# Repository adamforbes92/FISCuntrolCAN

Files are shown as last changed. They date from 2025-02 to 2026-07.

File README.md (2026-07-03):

# FISCuntrolCAN

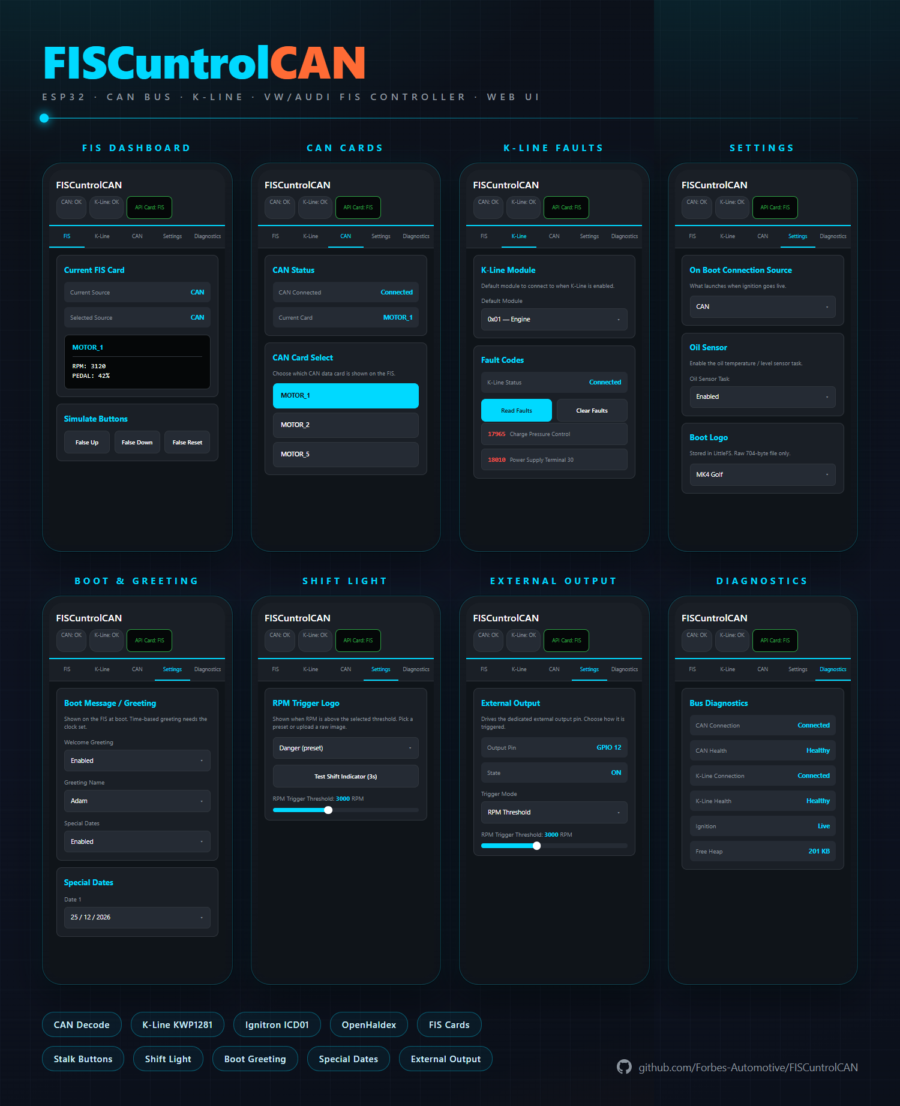
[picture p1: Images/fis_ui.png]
FISCuntrolCAN web UI


FISCuntrolCAN turns the **FIS** — the driver-information display in the middle of a VW/Audi instrument cluster — into a live data screen for your engine and chassis. It reads the car's **chassis CAN bus** (speed, RPM, pedal, Haldex, EML/EPC) and can also talk **KWP1281 over K-line** for diagnostic measuring blocks and fault codes, then displays it all onto the cluster as scrollable "cards" you flick through with the wiper-stalk buttons. It additionally decodes a standalone **Ignitron** ECU broadcast, co-operates with an **OpenHaldex** controller, and is configured entirely from a phone over **Wi-Fi** — no laptop or serial cable needed in the car. OTA updates and live diagnostics.

It is based on an **ESP32 DevKit V1 (WROOM-32)** running the Arduino framework, and is built around the excellent [TLBFISLib](https://github.com/domnulvlad/TLBFISLib), [KLineKWP1281Lib_ESP32](https://github.com/domnulvlad/KLineKWP1281Lib_ESP32) and [TLBLib](https://github.com/domnulvlad/TLBLib) libraries by `domnulvlad`, which implement the proprietary 3-wire FIS protocol and the KWP1281 diagnostic protocols.

---

## Features at a Glance

| Feature | Detail |
|---|---|
| CAN input | 500 kbit/s TWAI, accept-all filter — VAG MOTOR / Haldex / Ignitron decoders |
| K-line input | KWP1281 measuring blocks + fault-code read/clear (Engine, Gearbox, ABS, Airbag, Cluster) |
| FIS output | Live "cards" drawn over the proprietary 3-wire FIS bus via a level shifter |
| On-screen menu | Stalk-button driven SOURCE menu (K-Line / CAN / Ignitron / Haldex / Settings / Exit) |
| Ignitron view | Decodes the dashCAN "ICD01" sensor broadcast on `0x600–0x604` into paged cards |
| OpenHaldex | Broadcasts mode + pedal threshold + override so a Haldex controller can co-operate |
| Stalk control | Mimics / pulses the three stalk-button outputs to drive the cluster's own menus |
| Wi-Fi UI | Web app — config, diagnostics, OTA |
| OTA updates | Firmware **and** filesystem (web UI) flashed from the browser |
| Boot screens | Selectable splash bitmaps, or a personalised time-of-day greeting |
| Special dates | Up to 5 custom multi-line messages shown on matching calendar days (override the logo) |
| Device clock | Browser-synced time (no NTP needed in AP mode), optional DS1307 RTC, persisted to EEPROM |
| RPM shift light | Full-screen logo overlay above a configurable RPM threshold |
| Oil sensor | Optional single-wire Hella/VAG G266 oil level + temperature decoder *WIP* |
| Power management | Auto Wi-Fi-off + CPU scaling 1 min after the last client disconnects |
| Remembers settings | Nav state and configuration stored to ESP32 Preferences (NVS) |

---

## Compatibility

Designed for VW/Audi clusters that carry a **FIS** driven by the 3-wire
(`ENA` / `CLK` / `DATA`) protocol — e.g. MK4 Golf / Bora, B5–B6 Passat, and
contemporary Audi A3 / A4 / TT clusters. CAN decoding targets the classic VAG
powertrain frame set (`MOTOR1/2/5`, `HALDEX`), and K-line targets KWP1281
control modules. The Ignitron view targets the dashCAN "ICD01" custom-CAN
broadcast.

> Frame IDs, decoders and calibration are car-specific. Treat the supplied
> decoders as a known-good MK4 baseline and adjust [`config.h`](include/config.h)
> to suit your vehicle.

---

## Hardware Overview

### External Interfaces

| Function | Part / circuit |
| --- | --- |
| CAN transceiver | TJA1050 / MCP2551 / SN65HVD230 — 500 kbit/s |
| K-line transceiver  | KWP1281-capable transceiver (e.g. L9637, MC33290) |
| FIS bus | 5 V cluster lines through a CJ74LVC4T245 level shifter (bidirectional `ENA`, unidirectional `CLK` / `DATA`) |
| Stalk buttons | One isolated input + one isolated output per stalk button (UP / DOWN / RESET) |
| Ignition sense | Resistor divider into GPIO 35 (ADC, with hysteresis) |
| External output | GPIO for switching an aux load via a driver |
| Optional RTC | DS1307 on I²C (SDA GPIO 21 / SCL GPIO 22) — enable with "Use RTC" in the UI |
| Optional oil sensor | 12 V → 3.3 V level-shifted PWM signal on GPIO 4 *WIP* |

### Pin Map

Defined in [`include/config.h`](include/config.h):

| Group | Signal | GPIO |
| --- | --- | --- |
| FIS (SPI) | CLK | 18 |
| | DATA (MOSI) | 23 |
| | ENA (CS) | 19 |
| | ENADIR (level-shifter direction)  | 32 |
| K-line | TX / RX | 17 / 16 |
| CAN / TWAI | RX / TX | 13 / 14 |
| Stalk in | UP / DOWN / RESET | 34 / 39 / 36 |
| Stalk out | UP / DOWN / RESET | 27 / 26 / 25 |
| Misc | Ignition (ADC) | 35 |
| | External output | 12 |
| | Oil sensor (optional) | 4 |
| | RTC I²C SDA / SCL (optional) | 21 / 22 |

> **Input-only pins:** GPIO 34 / 36 / 39 have no internal pull-ups. The PCB
> must supply the pull-ups for the stalk inputs and the ignition-sense divider.

### Board

The reference hardware is the **FISCuntrol V3** board (Forbes Automotive),
built around an ESP32 DevKit V1 (WROOM-32) with an on-board switching
regulator, CAN and K-line transceivers, the FIS level shifter, and a single
18-way MX23A18NF1 connector.

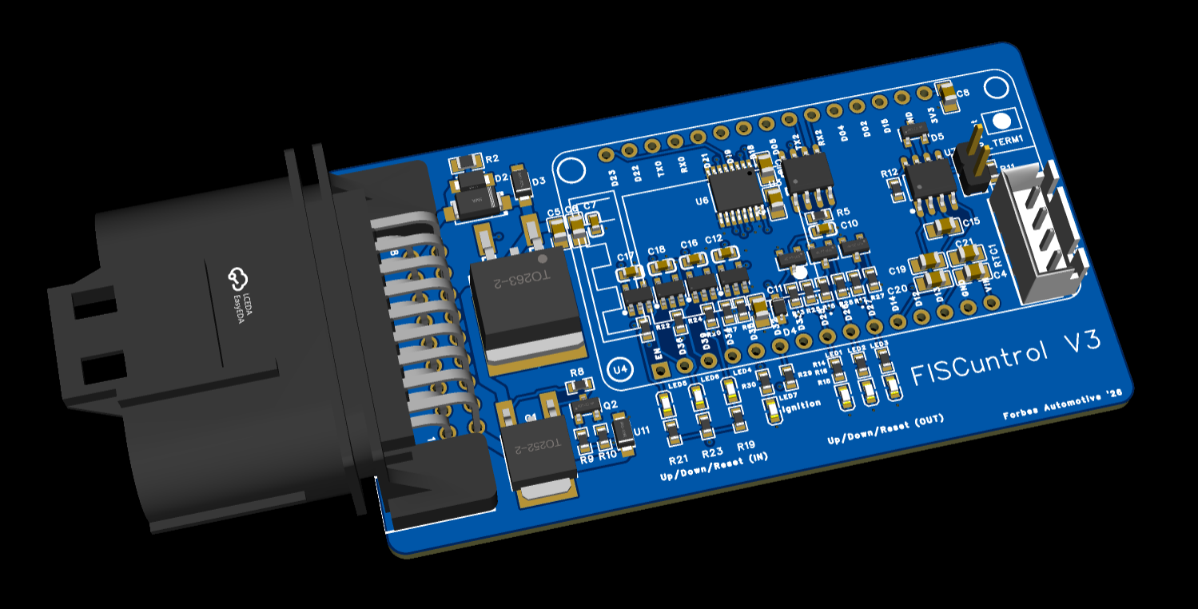
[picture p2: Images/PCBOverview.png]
FISCuntrol V3 board overview


### Harness Connector

All vehicle wiring lands on one **18-way** MX23A18NF1 connector (two rows of 9). Pin 1 is
top-right, pin 9 top-left; pin 10 is bottom-right, pin 18 bottom-left when
looking into the mating face.

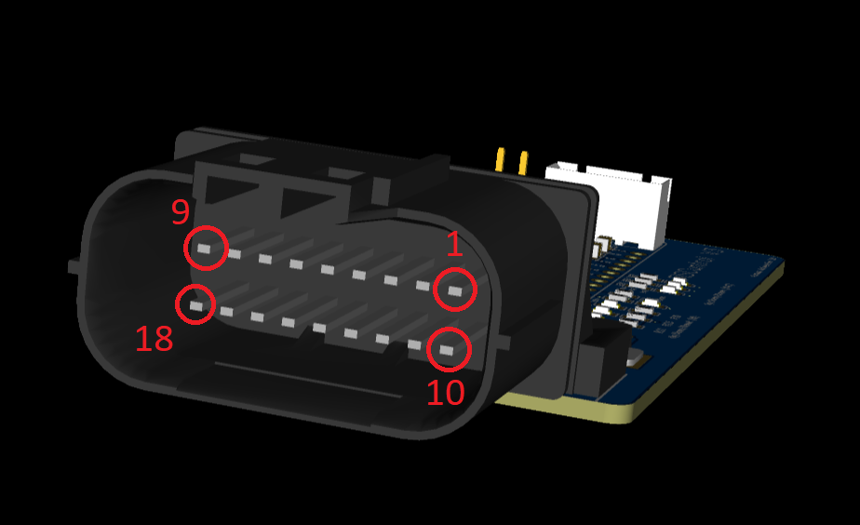
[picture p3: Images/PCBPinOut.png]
Connector pin numbering


| Pin | Silk name | Function | Internal net / GPIO |
| --- | --- | --- | --- |
| 1 | `EXT_OUT` | Switched external / aux output | GPIO 12 |
| 2 | — | Not connected | — |
| 3 | — | Not connected | — |
| 4 | `IN_UP_CONN` | Stalk **UP** button input | GPIO 34 |
| 5 | `IN_DOWN_CONN` | Stalk **DOWN** button input | GPIO 39 |
| 6 | `IN_RESET_CONN` | Stalk **RESET** button input | GPIO 36 |
| 7 | `OUT_UP_CONN` | Stalk **UP** output (drive to cluster) | GPIO 27 |
| 8 | `OUT_DOWN_CONN` | Stalk **DOWN** output (drive to cluster) | GPIO 26 |
| 9 | `OUT_RESET_CONN`  | Stalk **RESET** output (drive to cluster)  | GPIO 25 |
| 10  | `CHASSIS_CANH` | Chassis CAN High | CAN transceiver (RX 13) |
| 11  | `CHASSIS_CANL` | Chassis CAN Low | CAN transceiver (TX 14) |
| 12  | `FIS_ENA_5V` | FIS **ENA** (5 V, bidirectional) | GPIO 19 via CJ74LVC4T245 |
| 13  | `FIS_DATA_5V` | FIS **DATA** (5 V) | GPIO 23 via CJ74LVC4T245 |
| 14  | `FIS_CLK_5V` | FIS **CLK** (5 V) | GPIO 18 via CJ74LVC4T245 |
| 15  | `MC33290_K` | K-line (KWP1281) via MC33290 transceiver | GPIO 17 / 16 (TX / RX) |
| 16  | `GND` | Ground | GND |
| 17  | `12V_IGN` | Ignition-switched 12 V (ignition sense) | ADC GPIO 35 (divider) |
| 18  | `12V_PERM` | Permanent 12 V supply | Regulator input |

<details>
<summary>Silkscreen close-ups</summary>

| Pins 1–6 · 10–15 | Pins 6–9 · 15–18 |
| --- | --- |
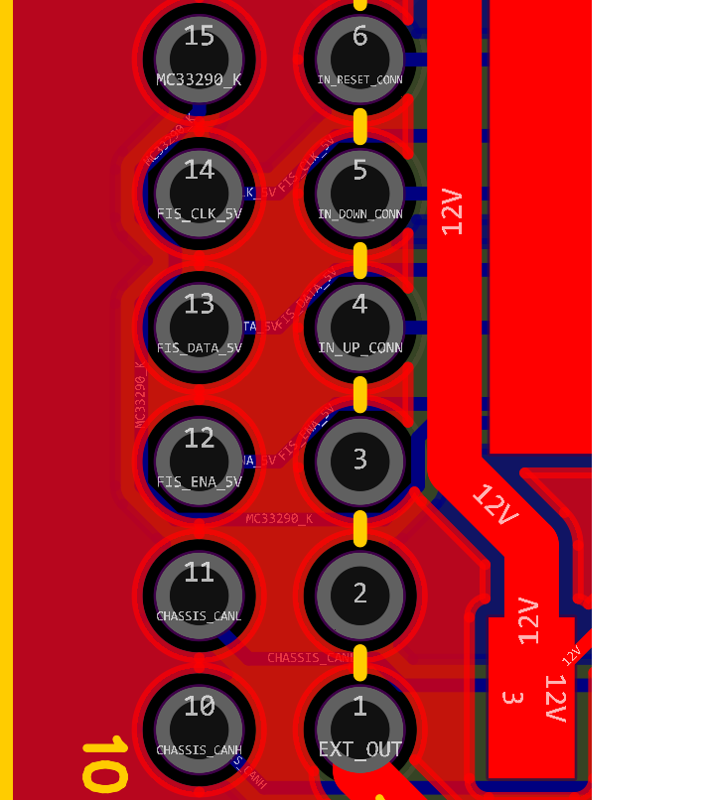
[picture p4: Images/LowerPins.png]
Lower connector pins
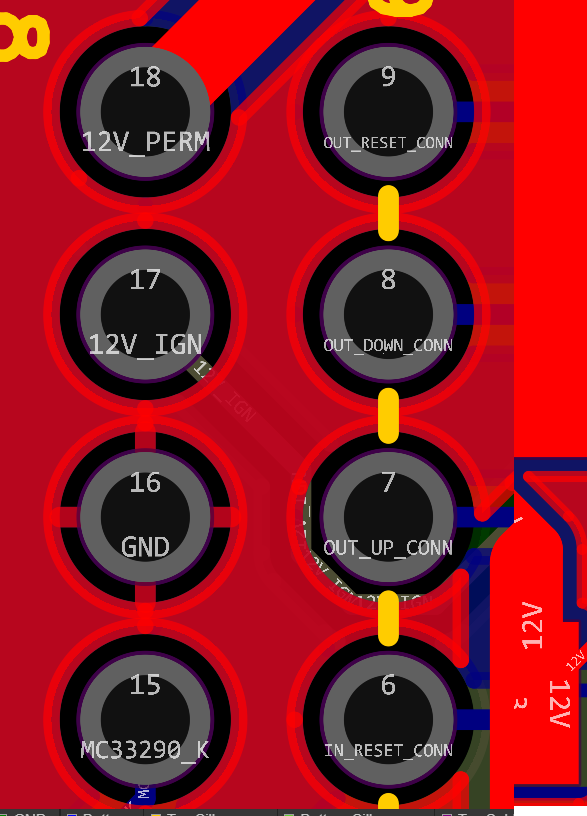
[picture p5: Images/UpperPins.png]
Upper connector pins
|  |  |

</details>

### Status LEDs

The board carries seven indicator LEDs for at-a-glance stalk and ignition I/O.

Stalk and ignition status LEDs

| LED | Group | Indicates |
| --- | --- | --- |
| LED1–LED3 | Up / Down / Reset **OUT**| Board is pulsing an output to the cluster |
| LED4–LED6 | Up / Down / Reset **IN** | A stalk button input is active |
| LED7 | Ignition | `12V_IGN` is live (ignition on) |

### CAN Termination &amp; RTC

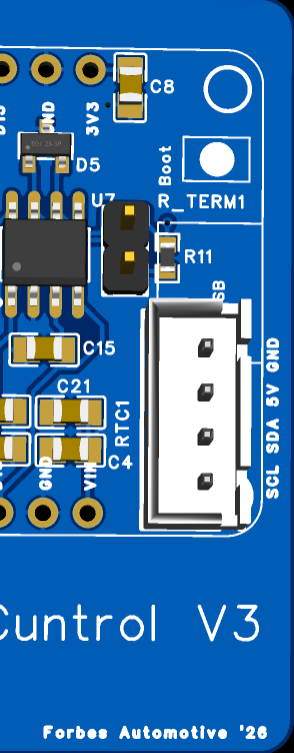
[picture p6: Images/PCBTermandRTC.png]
CAN termination jumper, boot button and RTC connector


| Feature | Detail |
| --- | --- |
| `TERM1` jumper | Fit to enable the **120 Ω** CAN bus termination; leave open when the board is not at the end of the bus |
| `RTC1` connector | 4-pin I²C header (`SCL` / `SDA` / `5V` / `GND`) for an optional DS1307 RTC module — enable with **Use RTC** in the UI (SDA GPIO 21 / SCL GPIO 22) |
| `BOOT` button  | ESP32 boot / flash button |

---

## How the Display Works

Multiple data sources feed a single shared "card" that the render task paints
onto the FIS. Only one source is shown at a time; the active source is chosen
by the on-screen menu and the stalk buttons.

```
CAN bus (500k)            K-line (KWP1281)        Ignitron ICD01 (0x600–0x604)
      │                         │                            │
      ▼ canTask (core 0)        ▼ klineTask (core 0)         ▼ canTask
 decode MOTOR1/2/5,        measuring blocks             capture frames,
 OpenHaldex, Ignitron      + fault codes                decode 16-bit signals
      │                         │                            │
      └────────────────┬────────┴────────────────────────────┘
                       ▼  shared globals  +  card store (FIS-line mutex)
                       ▼  parseFIS()  →  fisLine[0..7]
                       ▼  fisRenderTask (core 1)
                       ▼  TLBFISLib  →  FIS cluster screen
```

### Card Sources

| Source | Shows |
| --- | --- |
| `CAN` | Decoded MOTOR cards — RPM & pedal, speed, EML/EPC, plus raw bytes  |
| `IGNITRON` | Paged Ignitron ICD01 sensor values (6 signals per card) |
| `K-LINE` | KWP1281 measuring-block values for the selected module |
| `HALDEX` | OpenHaldex mode, lock target, engagement, speed, pedal |

### On-Screen Menu

Long-press **RESET** opens the **SOURCE** menu. Items appear only when their
hardware is available:

`K-LINE` (→ module sub-menu) · `CAN` · `IGNITRON` · `HALDEX` · `EXIT`

### Stalk Buttons

The three stalk buttons are read with [OneButton](https://github.com/mathertel/OneButton)
(single / double / long-press) and their meaning depends on the active source:

| Gesture | In a menu | CAN / Ignitron | Haldex | K-line |
| --- | --- | --- | --- | --- |
| UP — single | Navigate up | Next card / page | Mode + | Block +1 |
| DOWN — single | Navigate down | Previous card / page | Mode − | Block −1 |
| UP — double | — | — | — | Block +10 |
| DOWN — double | — | — | — | Block −10 |
| UP — long | — | **Toggle CAN ↔ OpenHaldex** (returns to the last CAN view) |||
| DOWN — long | — | — | — | Block → 1 |
| RESET — single | Select item | Open menu | Open menu | Open menu |
| RESET — long | Close menu | Open menu / re-enable FIS (toggles FIS off if not booted) |||

> **Last-CAN-view memory:** the long-press-UP toggle simply flips between
> OpenHaldex and the CAN view you last selected. If you were on `CAN` it
> toggles CAN ↔ OpenHaldex; if you were on `IGNITRON` it toggles
> Ignitron ↔ OpenHaldex. The choice persists across power cycles (EEP).

---

## Data Sources

### CAN Decoders

The TWAI controller runs at **500 kbit/s** with an accept-all filter, so every
frame on the bus reaches the firmware. Built-in VAG decoders:

| Frame | ID | Decoded into |
| --- | --- | --- |
| `MOTOR1` | `0x280` | `vehicleRPM`, `pedValue` |
| `MOTOR2` | `0x288` | `vehicleSpeed` (km/h, optional → mph) |
| `MOTOR5` | `0x480` | `vehicleEML`, `vehicleEPC` |
| `openHaldex`  | `0x6B0` | Haldex state, engagement, mode, speed |
| Ignitron ICD01| `0x600`–`0x604` | See [Ignitron View](#ignitron-view) |

### K-line (KWP1281)

When the boot source is K-line, the firmware connects to a control module over
the K-line and polls measuring blocks. The menu's **K-LINE** sub-menu selects
the module; reconnects are handled live with ret/fallback.

| Module  | Address |
| --- | --- |
| Engine  | `0x01`  |
| Gearbox | `0x02`  |
| ABS | `0x03`  |
| Airbag  | `0x22`  |
| Cluster | `0x23`  |

Fault codes can be read and cleared from the web UI's **K-Line** tab.

### Ignitron View

The Ignitron standalone ECU broadcasts the dashCAN **"ICD01"** custom message
set on frames `0x600–0x604`. Each frame packs four little-endian 16-bit
signals; FISCuntrolCAN captures the frames, decodes the signals (reversing the
dashCAN scale/offset) and shows them as paged cards — **6 signals per card**,
so the 20-signal map fills four pages (`IGN 1/4` … `IGN 4/4`). Page with the
UP/DOWN stalk buttons.

Decoded signals include RPM, coolant, MAP, IAT, EGT, oil pressure/temperature,
fuel rail pressure, lambda, pedal, speed, throttle position, battery voltage,
ignition advance, short/long fuel trims and ECU torque. 

### OpenHaldex

When Haldex hardware is present, a background task broadcasts a FISCuntrol
frame (`0x6A0`) carrying the selected mode every 50 ms, and reads the
OpenHaldex status frame (`0x6B0`). Modes: **Stock, FWD, 50/50, 60/40, 75/25,
Expert**. Change mode with UP/DOWN while the Haldex card is shown.

---

## Wi-Fi & Web Interface

Connect to the **`FISCuntrolCAN`** Wi-Fi access point and browse to
**`http://192.168.1.1/`**. The interface is a web app served from the
ESP32's LittleFS partition; settings auto-save to NVS.

| Tab | Purpose |
| --- | --- |
| **FIS** | Live FIS card preview, software stalk-button simulator, ignition restart |
| **K-Line** | Fault-code viewer + clear, module selector |
| **CAN** | CAN data card carousel |
| **Settings** | Boot source (CAN / K-line), boot screen, welcome greeting + name, special dates, Use RTC, per-category logging toggles, RPM-logo threshold, pin assignments, K-line default module |
| **Logos** | Upload a 704-byte boot bitmap or RPM-overlay bitmap |
| **Diagnostics** | CAN / K-line health, ignition state, free heap, FIS boot readiness, raw button-pin states, external-output control, device clock (browser / device / RTC time + RTC status) |
| **OTA** | Flash new firmware or a new filesystem image from the browser |

---

## Boot Greeting, Special Dates & Clock

The boot screen can show a **personalised greeting** instead of a logo. With
**Welcome Greeting** enabled in the **Settings** tab you enter a name only and
the device uses the time of day — `GOOD MORNING / AFTERNOON / EVENING
<name>`. The greeting and a boot logo are mutually exclusive (turning the
greeting on clears the selected logo).

**Special Dates** let you define up to **five** calendar days, each with its own
custom multi-line message. On a matching day the message is shown on boot and
**overrides the logo** for that day — even if the Welcome Greeting is off. A
date left at the `1970` is treated as unset.

Both features need the clock time. The browser POSTs its local
date/time to `/api/time` on every page load, the ESP32 advances that time with
its internal clock and **persists it to EEP** so a reboot still has an
approximate time. Enable **Use RTC** to additionally read/write a **DS1307**
on `SDA = GPIO 21` / `SCL = GPIO 22`; when present and running the RTC is
preferred on boot and kept in sync whenever the browser sets the time.

The **Diagnostics** tab's *Device Clock* panel shows the live **browser** time,
the **device** time, the **RTC** time, and the **RTC status**
(*Healthy* / *Not healthy* / *Not detected*). All greeting, special-date,
name and Use-RTC settings are stored in EEP.

---

## Power Management

The firmware bundles the universal `power_manager` module (shared with
SpeedPulser Pro / Can2Cluster) that **1 minute after the last
Wi-Fi client disconnects** will reduce CPU usage and turn off WiFi.  This reduces power consumption / heat generated.

| Action | Saving |
| --- | --- |
| Wi-Fi radio off | ~80–120 mA average (single biggest) |
| CPU 240 MHz → 80 MHz | Moderate reduction in active current |
| Bluetooth controller released at boot | ~60 KB RAM freed; small idle saving |
| Onboard LED off at boot | Tiny but persistent saving |

A power-cycle (ignition off/on) brings Wi-Fi back.

---

## Oil Sensor (Optional)
**Work In Progress!**
Decodes a single-wire Hella / VAG combined **oil-level + oil-temperature**
sensor (G266 family, OE PNs around `1J0907660*` / `06A907660*`). Disabled by
default (`hasOilSensor 0`).

- The sensor is treated as a **continuous ~18–30 Hz PWM** (not the BMW/Hella
  3-pulse frame): each cycle's **period** is mapped to oil temperature via a
  two-point linear fit, then EMA-filtered.
- The temperature fit is seeded from real MK4 G266 captures
  (~36.5 ms ≈ 20 °C, ~54 ms ≈ 100 °C). Re-check it against a dash / CAN
  oil-temperature reading.
- Oil **level** is *not* calibrated yet (`oilSensorLevelCalibrated 0`, level
  returns `NAN`) — the captures were made in water with the level pad dry.

**To calibrate:**

1. In [`config.h`](include/config.h) set `hasOilSensor 1` and `oilSensorRawLog 1`.
2. Wire the sensor's signal via a 12 V → 3.3 V level shifter to GPIO 4
   (change `oilSensorPin` for a different GPIO).
3. Watch Serial — every cycle prints
   `[OIL] period=… us (… Hz)  high=… us  low=… us  duty=…%  T=…C  cyc=… err=…`.
4. Tune the `oilSensor*` defines (`oilSensorTempPeriod0Us/…1Us` for temperature;
   the `…Period…/…Pulse…Min/Max` sanity windows) until `oilSensorFrameCount`
   rises and the temperature looks sane. For level, run an oil-bath depth test,
   set `oilSensorLevelCalibrated 1` and fill in `oilSensorLevelPulse0Us/…1Us`.

```cpp
void  setupOilSensor();                 // call from setup()
void  serviceOilSensor();               // call from loop()
float oilSensor_getTemperatureC();      // NAN if stale
float oilSensor_getLevelMm();           // NAN if stale
float oilSensor_getLevelPercent();      // 0..100, NAN if stale
bool  oilSensor_isPresent();
bool  oilSensor_hasValidReading();
```

---

## Configuration

### Feature Toggles

| Define | Default | Effect |
| --- | --- | --- |
| `enableDebug` | 1 | Mirror `DEBUG(...)` output to Serial. |
| `serialBaud` | 115200  | UART speed for the debug console. |
| `ChassisCANDebug` | 0 | Print every incoming TWAI frame. |
| `checkLED` | 0 | Run a one-shot LED test at boot. |
| `detailedDebugWiFi` | 0 | Verbose Wi-Fi events. |
| `hasRTC` | 0 | Legacy compile flag; the DS1307 RTC is now toggled at runtime via **Use RTC** in the UI. |
| `isMPH` | 1 | Convert km/h → mph (`mphFactor` constant). |
| `hasOilSensor` | 0 | Compile in the oil-sensor decoder. |
| `oilSensorRawLog` | 0 | Print every decoded oil-sensor pulse to Serial. |
| `defaultBootScreen` | 2 | 0=off, 1=text, 2=MK4Golf, 3=logo, 4=finger, 5=BMP.  |

### Timing Knobs

`fisWakeDelay`, `fisBootTimeoutMs`, `bootScreenDuration`, `logFrequency`,
`canRefresh`, `connectionDelayDuration`, `fisStatusCardHoldMs` — tune per car
if the cluster behaves differently.

---

## Software Architecture

The Arduino `loop()` runs on **core 1**; CAN reception and other long-lived
jobs run as dedicated FreeRTOS tasks on **core 0**.

### Modules

| Module | Responsibility |
| --- | --- |
| `config.*` | All compile-time defines, pin map, CAN IDs, shared globals + `extern` decls |
| `main.cpp` | `setup()` / `loop()`, ignition status, button-output + oil-sensor monitoring |
| `onboot.cpp`  | GPIO init, boot sequence, connection launch/shutdown |
| `tasks.cpp` | FreeRTOS task creation (CAN RX, FIS render, K-line poll, Haldex broadcast)  |
| `can_bus.cpp` | TWAI driver + frame capture; MOTOR + Ignitron card decode/render |
| `kline.cpp` | KWP1281 measuring-block reads + fault-code clear via Serial2 |
| `fis_display.cpp` | TLBFISLib wrapper + rendering |
| `fis_menu.cpp`| On-FIS SOURCE menu |
| `cards.cpp` | FIS "card" store with source switching (mutex-protected) |
| `buttons.cpp` | OneButton wrappers for the stalk inputs + stalk-output pulse generator |
| `bootLogos.cpp` / `bootmessage.cpp` | Boot splash bitmaps + user-configurable greeting / special-date messages |
| `timekeeper.cpp` | Device clock — browser time sync, optional DS1307 RTC, EEP |
| `web_server.cpp` | Wi-Fi AP + AsyncWebServer, JSON API, OTA, LittleFS-served UI |
| `oil_sensor.cpp` | Optional Hella oil-level + temperature decoder |

### FreeRTOS Tasks

| Task | Core | Priority | Job |
| --- | ---- | --- | --- |
| `CAN_RX` | 0 | 2 | Drain TWAI, update telemetry globals, feed Ignitron |
| `FIS_RENDER` | 1 | 2 | Render menu / card / RPM overlay / K-line / Haldex |
| `KLINE_POLL` | 0 | 1 | Poll KWP1281 measurements, handle module reconnect |
| `OH_BCAST` | 0 | 1 | Broadcast OpenHaldex frame (50 ms cadence) |

### `setup()` Order

1. `Serial.begin()` (if `enableDebug` / `ChassisCANDebug`)
2. `setupWiFi()` → `setupWebServer()` → `timeInit()`
3. `powerInit()` — start the background power-manager task
4. `initCardMutex()` — **before** any task that calls `commitCard()` / `displayFIS()`
5. `setupPins()` — GPIO directions, pull-ups, external output
6. `setupButtons()` — stalk OneButton handlers + ISRs
7. `setupOilSensor()` — attaches the edge ISR if `hasOilSensor` is on
8. `startTasks()` — launch the FreeRTOS tasks above

### `loop()` Services

ADC ignition sampling with hysteresis (20 ms) · button-output pulse servicing ·
oil-sensor pulse decode · ignition rise/fall → boot/shutdown · FIS enable/disable
toggle · 200 ms diagnostic Serial print.

---

## Technical Reference

### CAN / TWAI

| Parameter | Value |
| --- | --- |
| Baud | 500 kbit/s |
| Mode | Normal, accept-all filter |
| Driver | ESP-IDF `driver/twai.h` (native) |

### Key CAN IDs

| ID | Use |
| --- | --- |
| `0x280` / `0x288` / `0x480` | VAG `MOTOR1` / `MOTOR2` / `MOTOR5` |
| `0x600`–`0x604` | Ignitron ICD01 sensor broadcast |
| `0x6A0` | FISCuntrol → OpenHaldex mode |
| `0x6B0` | OpenHaldex → FISCuntrol status |

### PlatformIO Dependencies

| Library | Purpose |
| --- | --- |
| `me-no-dev/ESPAsyncWebServer` + `me-no-dev/AsyncTCP` | Async web server + TCP |
| `bblanchon/ArduinoJson` | JSON for the REST API |
| `mathertel/OneButton` | Stalk-button gesture decoding |
| `adafruit/RTClib` | Optional DS1307 RTC |
| `domnulvlad/TLBFISLib`  | FIS rendering over the 3-wire bus |
| `domnulvlad/KLineKWP1281Lib_ESP32` | KWP1281 diagnostic stack |
| `domnulvlad/TLBLib` | Low-level FIS transport |

Platform: `pioarduino/platform-espressif32` 54.03.20 (Arduino-ESP32 3.x / ESP-IDF 5.x).

---

## Version History

| Version | Highlights |
| --- | --- |
| **Unreleased** | Personalised boot **Welcome Greeting** (name only; device adds the time-of-day prefix) and **5 configurable special-date** messages that override the boot logo. New **timekeeper** module: browser-synced device clock (`/api/time`), optional **DS1307 RTC** on SDA 21 / SCL 22, and NVS persistence of the epoch. **Diagnostics** gained a *Device Clock* panel showing browser / device / RTC time plus RTC health. All new settings persisted to NVS. |
| **Logging & task refactor** | Categorised serial/UI logging (**SYS / CAN / K-LINE / IO / WIFI**) with per-category toggles in the UI; `parseFIS()` moved into `fis_display`, CAN tasks consolidated into `can_bus`; dedicated FreeRTOS tasks for ignition fallback, button outputs and the (UI-disable-able) oil sensor. |
| **Baseline** | CAN + K-line + Ignitron + OpenHaldex unified card system, Wi-Fi single-page UI, OTA (firmware + filesystem), RPM shift-light overlay, optional oil-sensor decoder and the shared power-management module. |

---

## Disclaimer

FISCuntrolCAN displays vehicle data for information only and interfaces with a
vehicle's diagnostic and CAN buses. Always assume readings are approximate.
Use at your own risk — incorrect frame IDs, decoders or wiring can affect bus
behaviour. Test on the bench before fitting to a car.

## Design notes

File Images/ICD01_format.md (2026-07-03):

# dashCAN `.icd` File Format (magic `ICD01`)

Reverse-engineered from `dashCAN_send_custom_CAN_Messages.icd` (2769 bytes) and
cross-checked field-by-field against the dashCAN "Import" UI. Every value below
was validated against the running tool.

## Conventions

- All multi-byte integers are **little-endian `uint32`**.
- The format is a set of **fixed-size parallel-array tables** ("columns").
  Each column is a flat array of `uint32`; row *i* of every column describes the
  same entry. A separate `uint32` count says how many rows are actually used;
  unused slots are left at their default value (often non-zero).
- Two tables exist: the **Identifier table** (the CAN frames to transmit) and
  the **Signal table** (the data packed into those frames).

## Top-level layout

| Offset  | Size | Meaning |
|---|---|---|
| `0x000` | 5 | Magic ASCII `"ICD01"` |
| `0x005` | 4 | `idCount` — number of identifiers used (here 5) |
| `0x009` | 448  | Identifier table: **7 columns × 16 rows × 4 bytes**|
| `0x1C9` | 4 | `sigCount` — number of signals used (here 20) |
| `0x1CD` | 2304 | Signal table: **9 columns × 64 rows × 4 bytes** |
| `0xACD` | 4 | Trailer / checksum (`0x000370E7` in this file) |
| `0xAD1` | — | EOF (2769 bytes total) |

`0x009 + 7*16*4 = 0x1C9` and `0x1CD + 9*64*4 = 0xACD`, so the sections abut exactly.

### Identifier table — base `0x009`, 16 rows/column, stride `16*4 = 0x40`

| Col | Offset  | Field | Notes |
|-----|---|---|---|
| 0 | `0x009` | CAN ID | 11-bit standard ID (0x600…0x604) |
| 1 | `0x049` | DLC / Length | Frame length in bytes (8) |
| 2 | `0x089` | Repeat | Repeat ÷10 → ms. `5` ⇒ **50 ms** |
| 3–6 | `0x0C9` | Reserved (zero)  | ID-type / data-init / flags — all 0 here|

### Signal table — base `0x1CD`, 64 rows/column, stride `64*4 = 0x100`

| Col | Offset  | Field | Notes |
|-----|---|---|---|
| 0 | `0x1CD` | Data type | dashCAN signal enum (see table below) |
| 1 | `0x2CD` | Multiply | Fixed-point ×1000. `1000` ⇒ **1.000** |
| 2 | `0x3CD` | Add (offset) | Raw integer offset added before scaling |
| 3 | `0x4CD` | Min | Raw clamp minimum |
| 4 | `0x5CD` | Max | Raw clamp maximum |
| 5 | `0x6CD` | Invert | 0 = normal, 1 = inverted |
| 6 | `0x7CD` | CAN ID | Which identifier this signal is packed into |
| 7 | `0x8CD` | Start bit | Bit offset within the frame (0,16,32,48…) |
| 8 | `0x9CD` | Length | Signal length in bits (16) |

Byte order is **little-endian** for all packed signals (matches the UI's
"Little endian" selection); it is not stored as a per-signal column in `ICD01`.

## Decoded contents of this file

**Identifiers** (all DLC 8, repeat 50 ms): `0x600 0x601 0x602 0x603 0x604`

**Signals** (type = dashCAN enum, scale = mul/1000, off = add):

| # | Signal name (UI) | enum  | CAN ID | start | len | mul | add  | min | max |
|---|---|---|---|---|-----|---|---|-----|---|
| 0 | Sensors RPM | 0x48  | 0x600  | 0 | 16  | 1.000 | 0 | 0 | 10000 |
| 1 | Sensors engine coolant temperature | 0x4B  | 0x600  | 16 | 16  | 1.000 | 400  | 0 | 1800  |
| 2 | Sensors manifold absolute pressure | 0x4A  | 0x600  | 32 | 16  | 1.000 | 0 | 0 | 10000 |
| 3 | Sensors intake air temperature | 0x4C  | 0x600  | 48 | 16  | 1.000 | 400  | 0 | 1800  |
| 4 | Sensors exhaust gas temperature | 0x4D  | 0x601  | 0 | 16  | 1.000 | 0 | 0 | 1200  |
| 5 | Sensors oil pressure | 0x62  | 0x601  | 16 | 16  | 1.000 | 0 | 0 | 10000 |
| 6 | Sensors oil temperature | 0x61  | 0x601  | 32 | 16  | 1.000 | 400  | 0 | 2000  |
| 7 | Sensors fuel rail pressure | 0x56  | 0x601  | 48 | 16  | 1.000 | 0 | 0 | 10000 |
| 8 | Sensors lambda | 0x4F  | 0x602  | 0 | 16  | 1.000 | 0 | 0 | 9999  |
| 9 | Sensors throttle pedal position | 0x58  | 0x602  | 16 | 16  | 1.000 | 0 | 0 | 10000 |
| 10| Sensors vehicle speed signal | 0x4E  | 0x602  | 32 | 16  | 1.000 | 0 | 0 | 3200  |
| 11| Sensors throttle position sensor | 0x59  | 0x603  | 0 | 16  | 1.000 | 0 | 0 | 10000 |
| 12| Sensors battery voltage | 0x53  | 0x603  | 16 | 16  | 1.000 | 0 | 0 | 10000 |
| 13| Ignition advance | 0x81  | 0x603  | 32 | 16  | 1.000 | 400  | 0 | 10000 |
| 14| Injection fuel trim (short term) | 0xED  | 0x603  | 48 | 16  | 1.000 | 1000 | 0 | 10000 |
| 15| Injection fuel trim (long term add.) | 0xEE  | 0x604  | 0 | 16  | 1.000 | 1000 | 0 | 10000 |
| 16| ECU Engine Output Power | 0x70  | 0x604  | 48 | 16  | 1.000 | 0 | 0 | 10000 |
| 17| Knock Amplitude | 0xF7  | 0x604  | 16 | 16  | 1.000 | 0 | 0 | 10000 |
| 18| ECU Engine Output Torque | 0x6F  | 0x602  | 48 | 16  | 1.000 | 0 | 0 | 10000 |
| 19| ECU Gear Number | 0x11B | 0x604  | 32 | 16  | 1.000 | 0 | 0 | 10000 |

### Decode/scale formula

Physical value the UI shows is derived from the raw 16-bit signal as:

```
raw   = signal bits (little-endian, unsigned)
value = (raw / multiply_fixed_x1000) ... then UI subtracts the "Add" offset
```

When *encoding* a physical value to transmit (the direction the dashboard uses):

```
raw = clamp( round(physical * (multiply/1000)) + add, min, max )
```

The `add` column is an integer pre-offset (e.g. coolant/IAT use +400 so a 0 °C
reading transmits as 400; trims use +1000 so 0 % transmits as 1000).

## dashCAN signal-type enum (the codes seen here)

| enum  | UI name |
|---|---|
| 0x48  | Sensors RPM |
| 0x4A  | Sensors manifold absolute pressure |
| 0x4B  | Sensors engine coolant temperature |
| 0x4C  | Sensors intake air temperature |
| 0x4D  | Sensors exhaust gas temperature |
| 0x4E  | Sensors vehicle speed signal |
| 0x4F  | Sensors lambda |
| 0x53  | Sensors battery voltage |
| 0x56  | Sensors fuel rail pressure |
| 0x58  | Sensors throttle pedal position |
| 0x59  | Sensors throttle position sensor |
| 0x61  | Sensors oil temperature |
| 0x62  | Sensors oil pressure |
| 0x6F  | ECU engine output torque |
| 0x81  | Ignition advance |
| 0xED  | Injection fuel trim (short term) |
| 0xEE  | Injection fuel trim (long term add.) |
| 0x70  | (unknown — not labelled in UI) |
| 0xF7  | (unknown — not labelled in UI) |
| 0x11B | (unknown — not labelled in UI) |

> Only the codes present in this file are mapped. The full dashCAN PID enum is
> larger; extend the table as new `.icd` files reveal more codes.

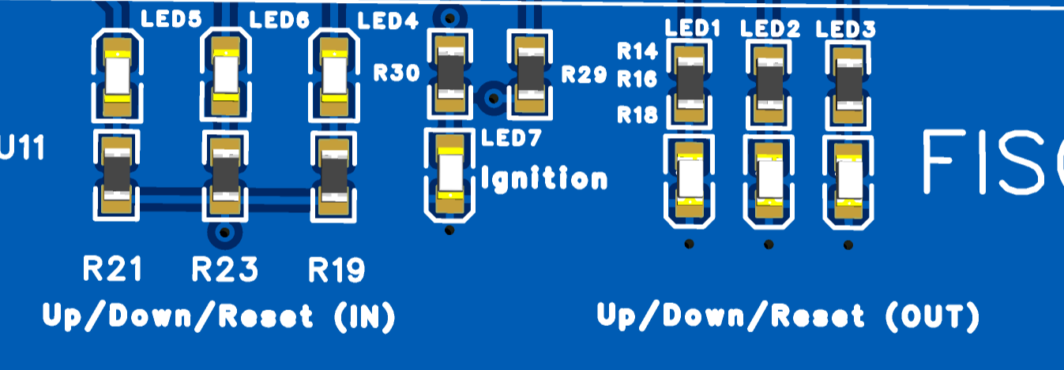
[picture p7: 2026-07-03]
Images/PCBStalkLEDs.png

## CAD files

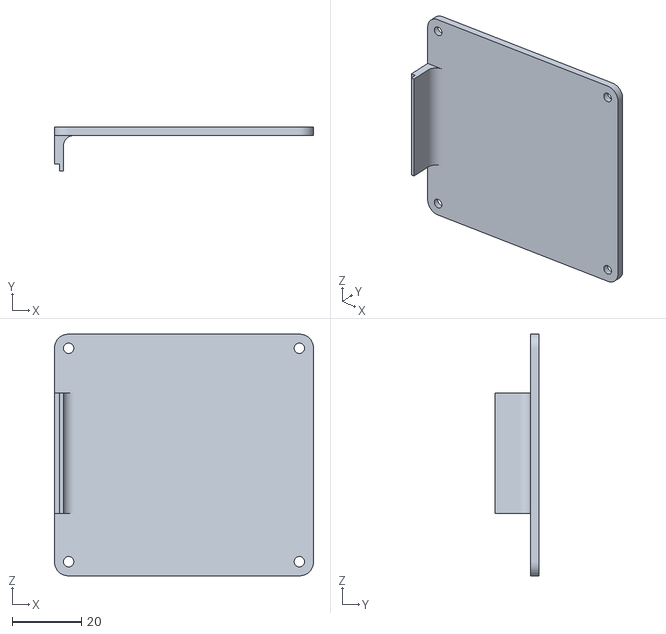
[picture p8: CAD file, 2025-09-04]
Enclosure/FISCuntrolLid.STL
75.0 x 12.6 x 70.0

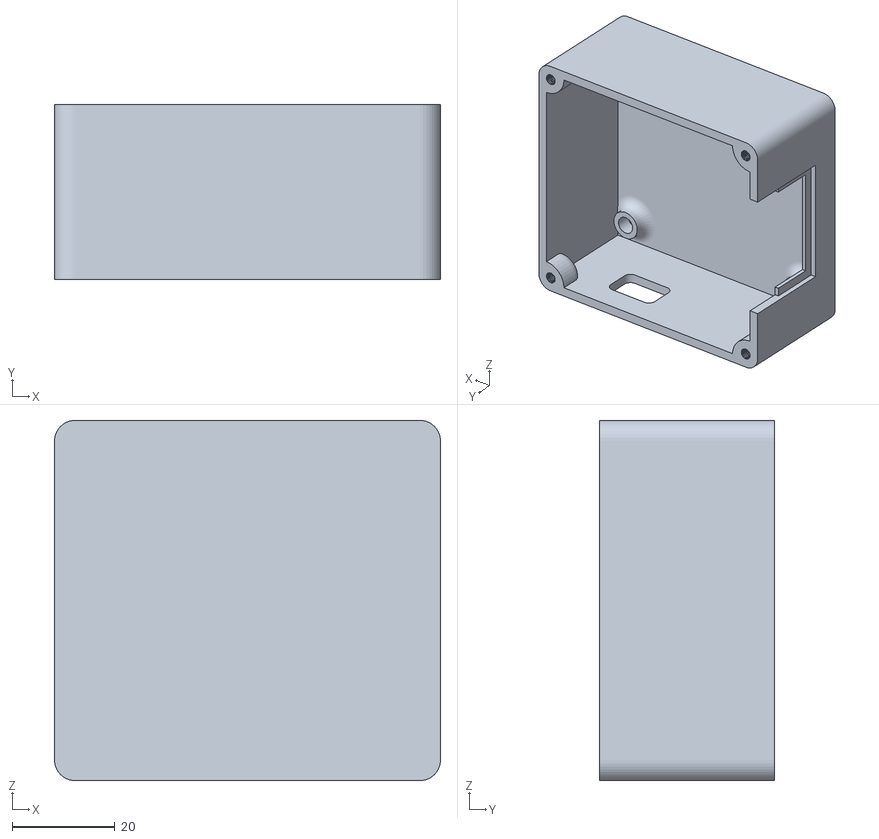
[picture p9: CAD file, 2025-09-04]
Enclosure/FISCuntrol.STL
75.0 x 34.0 x 70.0

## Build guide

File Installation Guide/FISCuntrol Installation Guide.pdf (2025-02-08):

## FISCuntrol Installation Guide

Forbes Automotive

## Contents

## Product Overview

Thank you for purchasing FISCuntrol by Forbes Automotive!

With all our products, this one is all opensource too – so you’re able to customise it to your needs. It supports custom boot messages which can be text-based or a custom logo. K-Line diagnostics, CANBUS and OpenHaldex are all supported, just select the options you have in the firmware.

The full range of options are:

- FIS Output
- Custom text-boot messages
- Custom boot logos
- K-Line
- For connection to various modules throughout the car (typically ECU)
- CANBUS
- In development, but for CAN based ECUs like Ignitron, a list of protocols to be developed
- OpenHaldex
- Pairs with OpenHaldex via. CAN messages to select or view current Haldex status
- OEM Controls
- Utilises the stock buttons for toggling through menus

At a minimum, the FISCuntrol can be used purely for boot messages and will therefore require the least amount of wiring.

## Wiring Installation

### Initial Setup

The module will come suppled with a plug only. It is the end user’s responsibility to make the final connections to the car depending on the required setup. This setup should then be paired with the appropriate firmware.

Pin Number | Basic Detail | Comments
1 | 12v Perm (K30) | Permanent power - for keeping the module awake - mainly for custom text/time based boot messages
2 | Reset (Cluster) | Reset button back to cluster
3 | 12v Ignition (K15) | Switched power (for waking up the module)
4 | Down (Cluster) | Down button back to cluster
5 | Ground (K31) | Ground - to chassis or similar
6 | Up (Cluster) | Up button back to cluster
7 | K-Line | K-Line (grey)
8 | Reset (Stalk) | Reset button to stalk
9 | FIS Clock | FIS Clock Wire (30)
10 | Down (Stalk) | Down button to stalk
11 | FIS Data | FIS Data Wire (31)
12 | Up (Stalk) | Up button to stalk
13 | FIS Enable | FIS Enable Wire (32)
14 | N/A | Not used
15 | CAN Low | CAN Low
16 | N/A | Not used
17 | CAN High | CAN High
18 | N/A | Not used

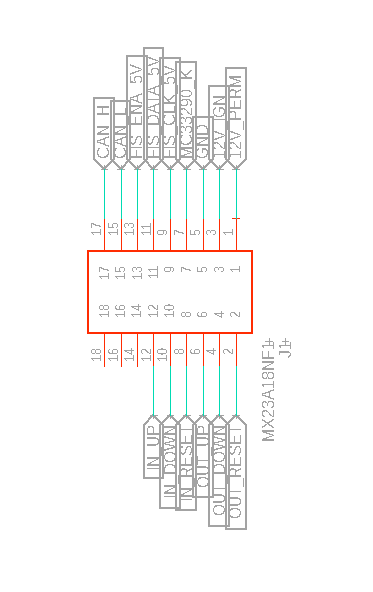
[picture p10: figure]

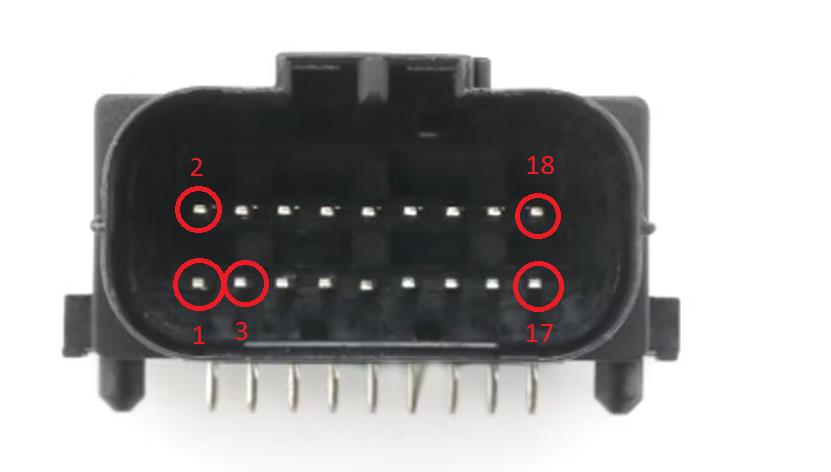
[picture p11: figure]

### Basic Operation

Using Stalk Buttons
If you have chosen to use the OEM stalk buttons as a means of interface, the default operation is to:
- Boot module, typically FIS Screen, welcome message
- Log into ECU via. K-Line or CAN
- Display variables
- ECU ‘Blocks’ can be toggled with the Up/Down buttons on the OEM stalk
- A long hold on the reset button will disable the controller to allow the OEM menus to be used

## Updating Software

Periodic firmware updates are available for download and can be uploaded to the OpenHaldex module with ease.

- Go to: https://github.com/adamforbes92/FISCuntrolCAN
- Choose the most recent software version
- Download and save locally
- Install Arduino IDE and open the downloaded software
- Ensure ESP is installed
- Use the ‘config.h’ page to adjust the features you wish to use

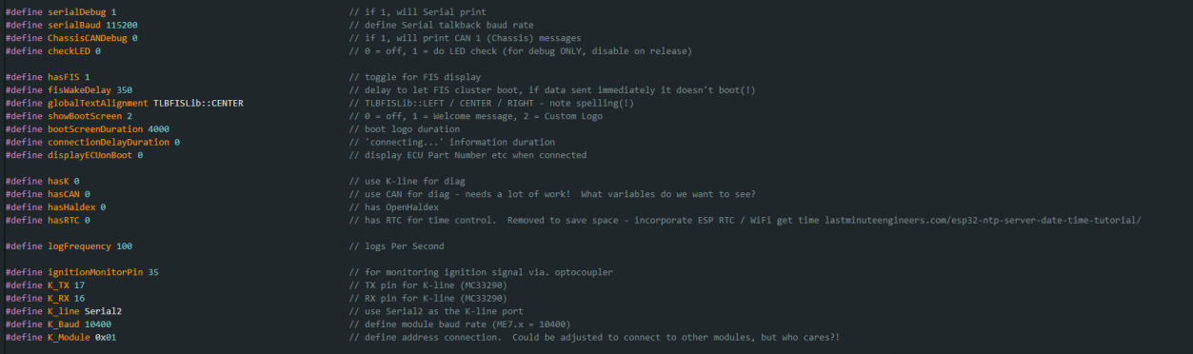
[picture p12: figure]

- From boards, select ESP32 DevKit and press compile and upload

## Disclaimer

DISCLAIMER:

Forbes Automotive is not responsible for any damage or loss that may occur to your vehicle or its contents during or after the installation of the FISCuntrol Module. By agreeing to use our product, you acknowledge that you have read and understand this disclaimer and agree to release Forbes Automotive from any liability for damages or losses.

LIMITATION OF LIABILITY:

In no event shall Forbes Automotive be liable for any direct, indirect, incidental, consequential, special, or punitive damages arising out of or in connection with the installation of the OpenHaldex T4 module, whether in contract, tort, strict liability, or any other legal theory.

This product is to be used in off-road applications only.

WARRANTY DISCLAIMER:

Forbes Automotive makes no warranties, express or implied, concerning the product, including but not limited to any warranties of merchantability or fitness for a particular purpose.

OTHER TERMS AND CONDITIONS:

By agreeing to use our services, you also agree to comply with any additional terms and conditions that may be provided to you by Forbes Automotive in connection with the product.

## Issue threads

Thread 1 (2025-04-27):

The code structure and PCB are not compatible

NesBow, 2025-04-27:
@adamforbes92 , Your code is oriented to ESP32 and the board FISCuntrol2_2024-07-14 is for MEGA PRO. Most likely the wrong PCB. I saw your new module works on ESP32

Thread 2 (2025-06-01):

Can IDs

adams-mk4-golf, 2025-06-01:
Following this, as I’m working on a canbus reader. If you need any help with the can ID addresses & functions then I can help.

adams-mk4-golf, 2025-06-02:
Hi Adam,
Please find motor can file attached. It took a long time to find & compile this data, and is the only known full list.I do have some from the comfort list too (from sniffing). I have a few notes on there, mainly the engine as there seem a few alternative IDs from older ECU to later ECU.
All addresses seem to check out.
I may need some help later on as I am not a programmer, if that would be OK
    On Monday 2 June 2025 at 19:28:25 BST, Forbes-Automotive ***@***.***> wrote:

 adamforbes92 left a comment (adamforbes92/FISCuntrolCAN#2)
Would be very handy! Currently CAN is quite bare - I'd like to build up 'blocks' to toggle through various addresses/bytes to form specific functions.

Will get messy etc with aftermarket ECUs, but worth padding out!

—
Reply to this email directly, view it on GitHub, or unsubscribe.
You are receiving this because you authored the thread.Message ID: ***@***.***>

adamforbes92, 2025-06-05:
There's nothing attached?

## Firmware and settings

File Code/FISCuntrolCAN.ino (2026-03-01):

/* 
FISCuntrol V3.0 - a MK4 based FIS controller based on an ESP32.  
> Uses the stock buttons for toggling menus
> Supports CAN-BUS and K-line diagnostic protocols for gathering data
> Supports OpenHaldex 
> Optional RTC for special dates & custom messages

Version history is '_vers.h'
*/

#include "FISCAN_config.h"

extern uint8_t readBlock = 1;

void sendFunctionFIS(uint8_t data) {
  SPI_INSTANCE.beginTransaction(SPISettings(125000, MSBFIRST, SPI_MODE3));
  SPI_INSTANCE.transfer(data);
  SPI_INSTANCE.endTransaction();
}
void beginFunctionFIS() {
  SPI_INSTANCE.begin();
}

// displays - LCD & FIS
TLBFISLib FIS(fisENA, sendFunctionFIS, beginFunctionFIS);

// communication - k-line & CAN
ESP32_CAN<RX_SIZE_256, TX_SIZE_16> chassisCAN;
#if serialDebug
KLineKWP1281Lib diag(beginFunction, endFunction, sendFunction, receiveFunction, K_TX, is_full_duplex, &Serial);
#else
KLineKWP1281Lib diag(beginFunction, endFunction, sendFunction, receiveFunction, K_TX, is_full_duplex);
#endif

openhaldexState state;
ESPAsyncHTTPUpdateServer updateServer;
AsyncWebServer server(80);

extern OneButton stalkUpButton(stalkPushUp, true);
extern OneButton stalkDownButton(stalkPushDown, true);
extern OneButton stalkResetButton(stalkPushReset, true);

// for repeated tasks (write to EEP & send status)
TickTwo tickSendOpenHaldex(broadcastOpenHaldex, canRefresh);

void IRAM_ATTR checkTicks() {
  // include all buttons here to be checked
  stalkUpButton.tick();     // just call tick() to check the state.
  stalkDownButton.tick();   // just call tick() to check the state.
  stalkResetButton.tick();  // just call tick() to check the state.
}

void setup() {
#if serialDebug || ChassisCANDebug
  Serial.begin(serialBaud);
  DEBUG_PRINTLN("ESP32 Initialisation...");
#endif

  setupPins();     // set pin inputs/outputs, do output test if req.
  setupButtons();  // set de-bounce times, etc
  launchBoot();
  launchConnections();
  setupWiFi();  // enable / start WiFi
  setupOTA();   // setup Over-the-Air updates

#if hasHaldex
  tickSendOpenHaldex.start();  // begin ticker for BT Status
#endif
}

void loop() {
#if hasHaldex
  tickSendOpenHaldex.update();  // refresh the BT Status ticker
#endif

  if (digitalRead(ignitionMonitorPin)) {
    ignitionState = true;
    triggerShutdown = true;
  } else {
    ignitionState = false;
  }

  if (!ignitionState && triggerShutdown) {
    beginShutdown();  // in '_onboot.ino'
  }

  // tick over the buttons
  stalkUpButton.tick();
  stalkDownButton.tick();
  stalkResetButton.tick();

  if (mimickSet) {
    DEBUG_PRINTLN("Turning off FIS...");
    fisDisablePrep();  // in '_onboot.ino'
  }

  if (fisDisable) {
    mimickStalkButtons();
  }

  if (ignitionState && !ignitionStateRunOnce && !fisDisable) {
    ignitionStateRunOnce = true;  // set ignStateRunOnce to stop redisplay of welcome message until ign. off.

    launchBoot();
    launchConnections();
  }

  if (ignitionState && !fisDisable) {
    // Get data from ECU, either via. K-line or CAN //
    if (hasK && !showHaldex && isConnectedK) {
      if (millis() - lastDataRetrieve >= logFrequency) {
        lastDataRetrieve = millis();
        // read K-Line
        if (readBlock > 255) {
          readBlock = 1;
        }
        showMeasurements(readBlock);
      }
    }

    if (hasCAN || showHaldex) {
      parseCAN();
    }
    // Get data from ECU, either via. K-line or CAN //

    // Display data from above capture
    //noInterrupts();
    if (hasFIS) {
      if (hasK && isConnectedK) {
        if (lastBlock != readBlock) {
          lastBlock = readBlock;
          FIS.clear();
          delay(fisWakeDelay);
        } else {
          displayFIS();
        }
      }

      if (hasCAN) {
        if (lastBlock != readBlock) {
          lastBlock = readBlock;
          FIS.clear();
          delay(fisWakeDelay);
        } else {
          displayFIS();
        }
      }

      if (hasHaldex) {
        if (lastHaldex != lastMode) {
          lastHaldex = lastMode;
          FIS.clear();
          delay(fisWakeDelay);
        } else {
          displayFIS();
        }
      }
    }
    // Display data from above capture
  }
}

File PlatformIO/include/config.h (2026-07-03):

#pragma once

/*
 * FISCuntrolCAN - Global Configuration
 * All compile-time defines, pin assignments, CAN IDs, and shared types.
 */

// ---------------------------------------------------------------------------
// Debug
// ---------------------------------------------------------------------------
#define enableDebug        1
#define serialBaud         115200
#define checkLED           0    // 1 = run LED output test on boot (debug only)

#include "logging.h"

// Categorised logging. Each macro routes to a runtime-toggleable category that
// gates output to BOTH serial and the UI log ring (see logging.h / logging.cpp).
//   DEBUG/LOGSYS -> [SYS]   LOGCAN -> [CAN]   LOGKLN -> [KLINE]
//   LOGIO -> [IO]           LOGWIFI -> [WIFI]
#if enableDebug
  #define DEBUG(x, ...)   logPrintf(LOG_SYS,   x, ##__VA_ARGS__)
  #define LOGSYS(x, ...)  logPrintf(LOG_SYS,   x, ##__VA_ARGS__)
  #define LOGCAN(x, ...)  logPrintf(LOG_CAN,   x, ##__VA_ARGS__)
  #define LOGKLN(x, ...)  logPrintf(LOG_KLINE, x, ##__VA_ARGS__)
  #define LOGIO(x, ...)   logPrintf(LOG_IO,    x, ##__VA_ARGS__)
  #define LOGWIFI(x, ...) logPrintf(LOG_WIFI,  x, ##__VA_ARGS__)
#else
  #define DEBUG(x, ...)
  #define LOGSYS(x, ...)
  #define LOGCAN(x, ...)
  #define LOGKLN(x, ...)
  #define LOGIO(x, ...)
  #define LOGWIFI(x, ...)
#endif

// ---------------------------------------------------------------------------
// Feature toggles
// ---------------------------------------------------------------------------
#define hasRTC     0    // Hardware RTC (DS1307)
#define isMPH      1    // Convert km/h readings to mph

// RTC (DS1307) I2C pins — used when "Use RTC" is enabled in the UI.
#define RTC_SDA_PIN  21
#define RTC_SCL_PIN  22

// ---------------------------------------------------------------------------
// Timing
// ---------------------------------------------------------------------------
#define fisWakeDelay           500    // ms delay after FIS power-on before sending data
#define fisBootTimeoutMs       1500   // max ms to wait for FIS init before continuing startup
#define fisStatusCardHoldMs    1800   // ms to keep redrawing transient status cards (e.g. K-line connecting)
#define bootScreenDuration     4000   // ms to show boot logo/message
#define connectionDelayDuration 0     // ms to show "connected" messages (0 = skip)
#define logFrequency           100    // K-line reads per second (ms between reads)
#define canRefresh             50     // ms between OpenHaldex CAN broadcasts

// ---------------------------------------------------------------------------
// FIS display
// ---------------------------------------------------------------------------
#include <TLBFISLib.h>

#define fisCLK   18   // SPI CLK  (default ESP32 VSPI CLK)
#define fisDATA  23   // SPI MOSI (default ESP32 VSPI MOSI)
#define fisENA    19  // SPI CS — ENA line (bidirectional, driven by TLBLib as INPUT/OUTPUT)
#define fisENADIR 32  // 2DIR on CJ74LVC4T245: HIGH = ESP32→FIS (A→B), LOW = FIS→ESP32 (B→A)
                      // 1DIR is hardwired to 3.3V — CLK and DATA are always A→B

#define screenSize           TLBFISLib::FULLSCREEN
#define globalTextAlignment  TLBFISLib::LEFT
#define SPI_INSTANCE         SPI

#define defaultBootScreen 2    // 0=off, 1=text welcome, 2=MK4Golf, 3=logo, 4=finger, 5=custom BMP
#define displayECUonBoot  0    // show ECU part number on successful K-line connect

// ---------------------------------------------------------------------------
// K-line
// ---------------------------------------------------------------------------
#define K_TX     17
#define K_RX     16
#define K_line   Serial2
#define K_Baud   10400
#define K_Module 0x01
#define is_full_duplex false

// ---------------------------------------------------------------------------
// CAN / TWAI pins
// ---------------------------------------------------------------------------
#define pinCAN_RX  13
#define pinCAN_TX  14
#define CAN_BAUD   500000   // 500 kbit/s

// ---------------------------------------------------------------------------
// Stalk buttons
// ---------------------------------------------------------------------------
#define stalkPushUp          34
#define stalkPushDown        39
#define stalkPushReset       36
#define stalkPushUpReturn    27
#define stalkPushDownReturn  26
#define stalkPushResetReturn 25

// ---------------------------------------------------------------------------
// Misc GPIO
// ---------------------------------------------------------------------------
#define ignitionMonitorPin 35
#define extOutputPin       12   // External Output — GPIO 12

// Ignition monitor uses ADC sampling on GPIO35 with hysteresis.
// Tune these values based on measured OFF/ON raw ADC values (0..4095).
#define ignitionAdcOnThreshold  2400
#define ignitionAdcOffThreshold 1600
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

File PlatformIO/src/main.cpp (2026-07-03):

/*
 * main.cpp — FISCuntrolCAN
 *
 * PlatformIO / Arduino-framework entry point for ESP32 DevKit V1.
 *
 * CAN receive runs in a dedicated FreeRTOS task (canTask, core 0).
 * The Arduino loop() runs on core 1 and handles:
 *   - Ignition monitoring
 *   - Button ticks
 *   - Ignition lifecycle handling
 *   - CAN data parsing → fisLine[]
 *   - FIS rendering
 */

#include <Arduino.h>
#include "config.h"

#include "web_server.h"
#include "fis_display.h"
#include "can_bus.h"
#include "buttons.h"
#include "onboot.h"
#include "tasks.h"
#include "cards.h"
#include "oil_sensor.h"
#include "power_manager.h"
#include "timekeeper.h"

// ---------------------------------------------------------------------------
// setup()
// ---------------------------------------------------------------------------
void setup()
{
#if enableDebug
    Serial.begin(serialBaud);
    logInit();   // start the categorised serial/UI logging task
    DEBUG("ESP32 FISCuntrolCAN initialising...");
#endif

    setupWiFi();
    setupWebServer();
    timeInit();   // device clock (browser-set; optional DS1307 RTC) — after settings load

    // Universal reduced-power module: turns WiFi off 1 min after the last client
    // disconnects, scales CPU 240->80 MHz, releases Bluetooth and kills the
    // onboard LED to cut current draw (and therefore linear-regulator heat).
    power_config_t pcfg = powerDefaultConfig();
    powerInit(&pcfg);

    initCardMutex();   // Must be before any task that calls commitCard() or displayFIS()
    setupPins();
    setupButtons();
    setupOilSensor();
    startTasks();
}

// ---------------------------------------------------------------------------
// loop()
//
// Ignition lifecycle, button-output pulsing and the oil sensor now run in
// dedicated FreeRTOS tasks (see tasks.cpp). loop() only services the OneButton
// stalk inputs (which must be polled frequently) and the FIS bypass path.
// ---------------------------------------------------------------------------
void loop()
{
    // --- Button polling ---
    stalkUpButton.tick();
    stalkDownButton.tick();
    stalkResetButton.tick();

    // --- FIS disable/re-enable ---
    if (fisBeenToggled)
    {
        noInterrupts();
        fisBeenToggled = false;
        interrupts();

        DEBUG("FIS disable toggled – prepping...");
        fisDisablePrep();
        DEBUG("FIS disable prep complete.");
    }

    if (fisDisable)
    {
        mimickStalkButtons();
        delay(1);
        return; // nothing else to do when bypassed
    }
    // Ignition lifecycle + FIS parsing/rendering run in dedicated tasks.
    delay(1);
}

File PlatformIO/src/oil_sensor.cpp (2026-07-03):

/*
 * oil_sensor.cpp — VAG / Hella MK4 Golf combined oil-level + temperature
 * sensor decoder (G266; Hella 6PR 008 079-xx, VAG 1J0 907 660x).
 *
 * SIGNAL MODEL — CONTINUOUS PWM (verified against scope captures):
 *
 *   The sensor drives a single signal line with a free-running square wave at
 *   roughly 18-30 Hz (~36-55 ms period). BOTH the period and the high-time
 *   grow as the sensor heats up:
 *
 *       ~20 C  : period ~36-37 ms (~27 Hz),  high ~9 ms
 *       ~100 C : period ~53-55 ms (~18 Hz),  high ~46 ms
 *
 *   There is NO ~780 ms sync gap and NO 3-pulse (Temp/Level/Diag) frame — that
 *   is a different part (the BMW/Hella "PULS" oil-condition sensor). This
 *   decoder therefore measures every cycle and maps PERIOD -> temperature.
 *
 *   Level is NOT decoded yet: the reference captures were taken in water with
 *   the level pad dry, so there is no valid pulse-width -> level mapping. Level
 *   output stays NAN until oilSensorLevelCalibrated is set (see config.h).
 *
 * Implementation:
 *   - The ISR timestamps every edge. On a falling edge it records the high-time
 *     of the pulse that just ended; on the next rising edge it has a complete
 *     cycle (rise-to-rise period + that high-time) and flags it for the
 *     foreground.
 *   - serviceOilSensor() lifts the cycle out under a brief critical section,
 *     range-checks it, converts period to temperature, and applies an
 *     exponential moving-average filter to smooth the ~20 Hz stream.
 *
 *   Compile with oilSensorRawLog = 1 to dump every cycle (period / high / low /
 *   duty / temperature) to Serial — use this on the car to refit the
 *   oilSensorTempPeriod* points and to gather data for the level calibration.
 */

#include <Arduino.h>
#include <math.h>
#include "config.h"
#include "oil_sensor.h"

// ---------------------------------------------------------------------------
// ISR-private state (only touched from oilSensorEdgeISR)
// ---------------------------------------------------------------------------
static volatile uint32_t isrLastRiseUs = 0;
static volatile uint32_t isrLastFallUs = 0;
static volatile uint32_t isrLastHighUs = 0;
static volatile bool     isrHaveRise   = false;

// ---------------------------------------------------------------------------
// Foreground decoder state (only touched from serviceOilSensor)
// ---------------------------------------------------------------------------
static float oilSensorTempFilt = NAN;   // EMA-filtered temperature

// ---------------------------------------------------------------------------
// Helpers
// ---------------------------------------------------------------------------
// Plain two-point linear map — NOT clamped, so temperature extrapolates
// sensibly below 20 C / above 100 C.
static float oilSensorMap(float x, float x0, float y0, float x1, float y1) {
    if (x1 == x0) return y0;
    return y0 + (x - x0) * (y1 - y0) / (x1 - x0);
}

static bool oilSensorReadingFresh() {
    if (oilSensorLastFrameMs == 0) return false;
    return (millis() - oilSensorLastFrameMs) < oilSensorStaleMs;
}

// ---------------------------------------------------------------------------
// ISR — fast, no floats, no Serial
// ---------------------------------------------------------------------------
void IRAM_ATTR oilSensorEdgeISR() {
    uint32_t nowUs = micros();
    uint8_t  level = (uint8_t)digitalRead(oilSensorPin);
    oilSensorLastEdgeMs = millis();

    if (level) {
        // Rising edge — a full cycle (previous rise -> this rise) just closed.
        if (isrHaveRise) {
            uint32_t periodUs = nowUs - isrLastRiseUs;
            oilSensorLastPeriodUs = periodUs;
            oilSensorLastPulseUs  = isrLastHighUs;
            oilSensorLastGapUs    = (periodUs > isrLastHighUs)
                                        ? (periodUs - isrLastHighUs) : 0;
            oilSensorPulseReady   = true;
        }
        isrLastRiseUs = nowUs;
        isrHaveRise   = true;
    } else {
        // Falling edge — close the high portion of the current cycle.
        if (isrHaveRise) {
            isrLastHighUs = nowUs - isrLastRiseUs;
        }
        isrLastFallUs = nowUs;
    }
}

// ---------------------------------------------------------------------------
// Foreground service — consume one completed cycle at a time
// ---------------------------------------------------------------------------
static void oilSensorDecodeCycle(uint32_t periodUs, uint32_t highUs) {
    // Reject glitches and lost cycles.
    if (periodUs < oilSensorPeriodMinUs || periodUs > oilSensorPeriodMaxUs ||
        highUs   < oilSensorPulseMinUs  || highUs   > oilSensorPulseMaxUs  ||
        highUs >= periodUs) {
        oilSensorErrorCount++;
#if oilSensorRawLog
        LOGIO("[OIL] period=%lu us  high=%lu us  -> OUT OF RANGE",
                      (unsigned long)periodUs, (unsigned long)highUs);
#endif
        return;
    }

    // Period -> temperature (linear, extrapolated), then EMA smoothing.
    float tInst = oilSensorMap((float)periodUs,
                               oilSensorTempPeriod0Us, oilSensorTempPeriod0C,
                               oilSensorTempPeriod1Us, oilSensorTempPeriod1C);
    if (isnan(oilSensorTempFilt)) {
        oilSensorTempFilt = tInst;
    } else {
        oilSensorTempFilt += oilSensorFilterAlpha * (tInst - oilSensorTempFilt);
    }
    oilSensorTemperatureC = oilSensorTempFilt;

#if oilSensorLevelCalibrated
    oilSensorLevelMm = oilSensorMap((float)highUs,
                                    oilSensorLevelPulse0Us, oilSensorLevelPulse0Mm,
                                    oilSensorLevelPulse1Us, oilSensorLevelPulse1Mm);
#else
    oilSensorLevelMm = NAN;   // not calibrated — see config.h
#endif

    oilSensorFrameCount++;
    oilSensorLastFrameMs = millis();

#if oilSensorRawLog
    float dutyPct = 100.0f * (float)highUs / (float)periodUs;
    LOGIO("[OIL] period=%lu us (%.1f Hz)  high=%lu us  low=%lu us  duty=%.1f%%  T=%.1fC  cyc=%lu err=%lu",
                  (unsigned long)periodUs,
                  (double)(1.0e6 / (double)periodUs),
                  (unsigned long)highUs,
                  (unsigned long)(periodUs - highUs),
                  (double)dutyPct,
                  (double)oilSensorTemperatureC,
                  (unsigned long)oilSensorFrameCount,
                  (unsigned long)oilSensorErrorCount);
#endif
}
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

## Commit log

2024-11-03 V3.0
    Mostly defined and entirely untested at this stage.
2025-01-19 V3.0
    Brought files together, removed Bluetooth because Haldex comms via. CAN anyway. Confirmed all buttons and new PCB work.
2025-01-20 Create FISCuntrol Board2_2024-07-14.zip
2025-06-02 V1.02
    Added pullup/pulldown where necessary. Added 560ohm pull up on K for multi-module (woops). Added correct PCB design.
    [FISCAN_CAN.ino, FISCAN_buttons.ino, FISCAN_config.h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]
2025-06-05 Added 7525 Haldex
    Added 7525 Haldex and fixed boot logo.
    [FISCAN_CAN.ino, FISCAN_buttons.ino, FISCAN_config.h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]
2025-09-04 Added enclosures
    [FISCuntrol.STL, FISCuntrolLid.STL]
